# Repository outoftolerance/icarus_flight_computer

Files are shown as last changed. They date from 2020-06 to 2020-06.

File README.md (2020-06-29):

# Icarus Flight Computer

## SERCOM
We make use of the SERCOM feature of the micro by definig two additional serial ports beyond those already defined by default, no other customised use of the SERCOM system is needed for this project.

*Note that when adding serial port interfaces using SERCOM, the TX pin may only reside on either PAD0 or PAD2 of a specific SERCOM interface! This limits the available SERCOM interfaces that we can choose from because some pads are being used for other interfaces (like I2C or SPI).*

The following table shows the pinout for the `ATSAMD21G18A-U` SERCOM and the uses that we are making of these pins for the project. This table was sourced from ADafruit's fantastic guide on using the Feather M0 that can be [found on their website](https://learn.adafruit.com/using-atsamd21-sercom-to-add-more-spi-i2c-serial-ports/overview).

|Microcontroller Pin|Arduino 'Pin'|SERCOM|SERCOM alt|Configured Interface|
|---|---|---|---|--|
|PA00|Used by xtal|SERCOM1.0|||
|PA01|Used by xtal|SERCOM1.1|||
|PB08|A1|SERCOM4.0|||
|PB09|A2|SERCOM4.1|||
|PA04|A3|SERCOM0.0|||
|PA05|A4|SERCOM0.1|||
|PA06|D8|SERCOM0.2|||
|PA07|D9|SERCOM0.3|||
|PA08|D4|SERCOM0.0|SERCOM2.0|Serial3 - Cellular|
|PA09|D3|SERCOM0.1|SERCOM2.1|Serial3 - Cellular|
|PA10|D1|SERCOM0.2|SERCOM2.2|Serial1 - GPS|
|PA11|D0|SERCOM0.3|SERCOM2.3|Serial1 - GPS|
|PB10|D23 / MOSI|SERCOM4.2||SPI - MicroSD|
|PB11|D24 / SCK|SERCOM4.3||SPI - MicroSD|
|PA12|D22 / MISO|SERCOM2.0|SERCOM4.0|SPI - MicroSD|
|PA13|Used by EDBC|SERCOM2.1|SERCOM4.1||
|PA14|D2|SERCOM2.2|SERCOM4.2||
|PA15|D5|SERCOM2.3|SERCOM4.3||
|PA16|D11|SERCOM1.0|SERCOM3.0|Serial2 - Radio|
|PA17|D13|SERCOM1.1|SERCOM3.1||
|PA18|D10|SERCOM1.2|SERCOM3.2|Serial2 - Radio|
|PA19|D12|SERCOM1.3|SERCOM3.3||
|PA20|D6|SERCOM5.2|SERCOM3.2||
|PA21|D7|SERCOM5.3|SERCOM3.3||
|PA22|D20 / SDA|SERCOM3.0|SERCOM5.0|I2C - Sensors|
|PA23|D21 / SCL|SERCOM3.1|SERCOM5.1|I2C - Sensors|
|PA24|Used by USB|SERCOM3.2|SERCOM5.2|Serial - Debug|
|PA25|Used by USB|SERCOM3.3|SERCOM5.3|Serial - Debug|
|PB22|D30 / EDBG TX|SERCOM5.2||Serial5 - APRS|
|PB23|D31 / EDBG RX|SERCOM5.3||Serial5 - APRS|
|PA30|Used by SWCLK|SERCOM1.2|||
|PA31|Used by SWDIO|SERCOM1.3|||
|PB02|A5|SERCOM5.0|||
|PB03|D25 / RX LED|SERCOM5.1|||

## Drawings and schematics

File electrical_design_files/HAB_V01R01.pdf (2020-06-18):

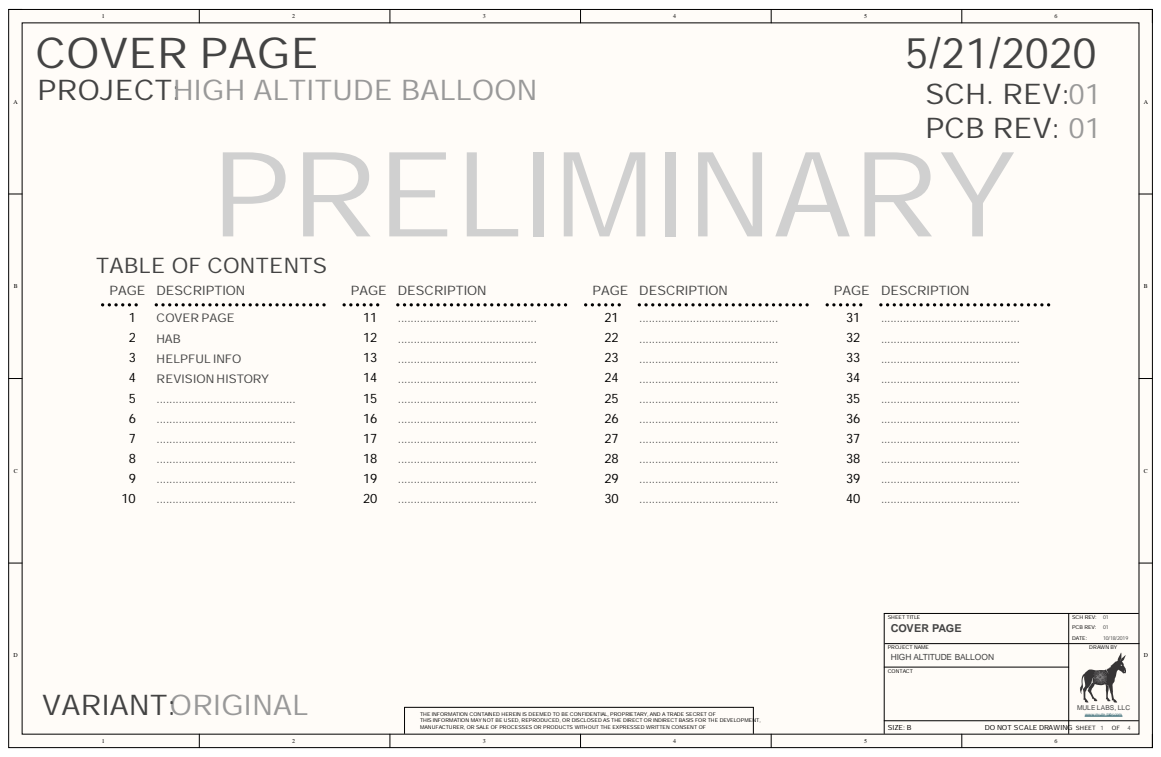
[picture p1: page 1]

SHEET TITLE COVER PAGE | SCH REV: 01 PCB REV: 01 DATE: 10/18/2019

PROJECT NAME HIGH ALTITUDE BALLOON | DRAWN BY MULE LABS, LLC www.mule-labs.com

THE INFORMATION CONTAINED HEREIN IS DEEMED TO BE CONFIDENTIAL, PROPRIETARY, AND A TRADE SECRET OF
THIS INFORMATION MAY NOT BE USED, REPRODUCED, OR DISCLOSED AS THE DIRECT OR INDIRECT BASIS FOR THE DEVELOPMENT,
MANUFACTURER, OR SALE OF PROCESSES OR PRODUCTS WITHOUT THE EXPRESSED WRITTEN CONSENT OF

DO NOT SCALE DRAWING

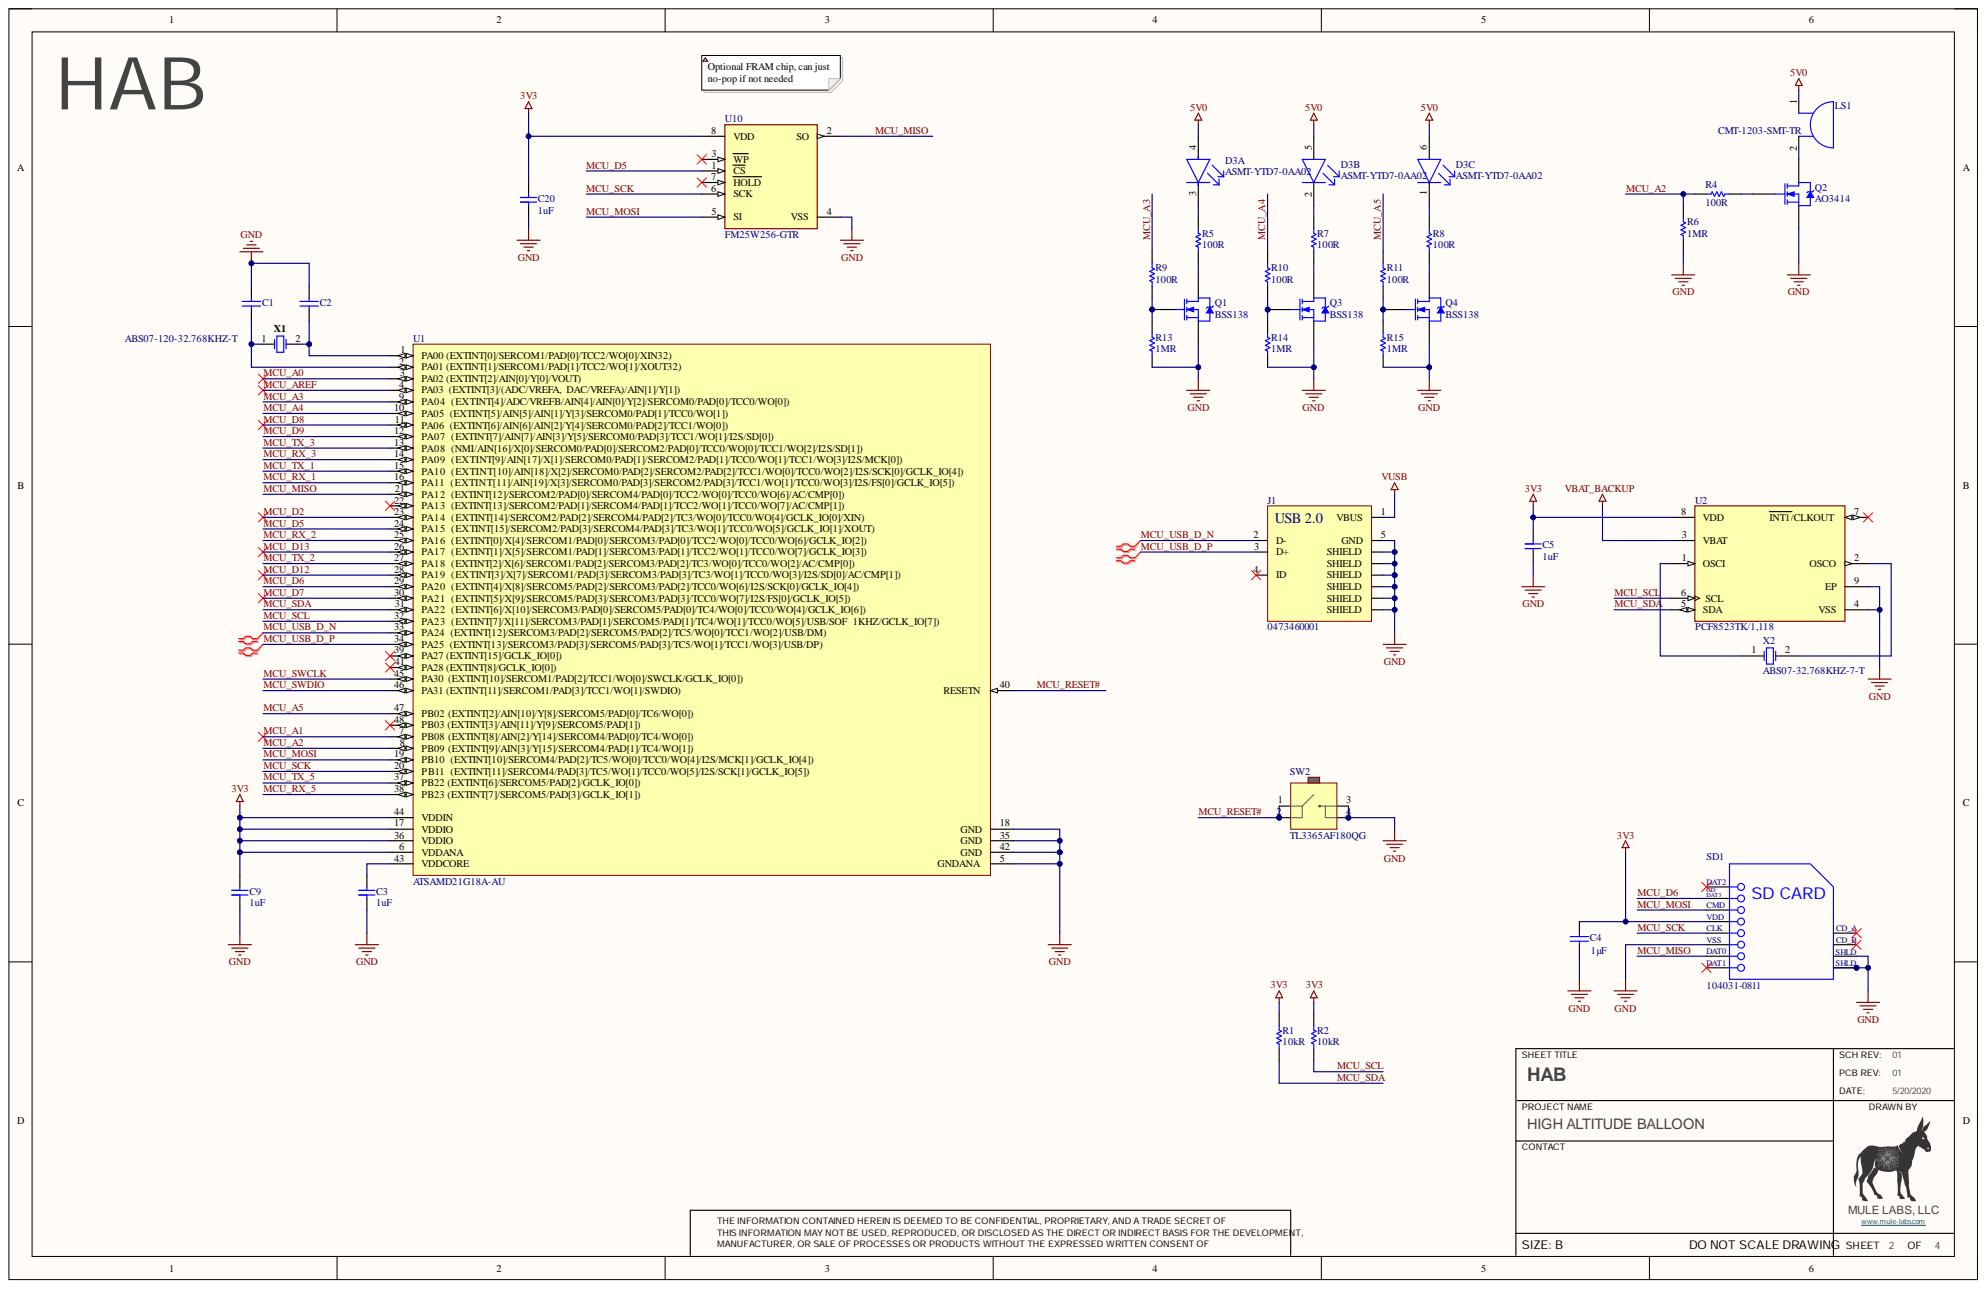
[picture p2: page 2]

3 6 | 3 5 | 1 R 2 0 kR 1 0 kR
6 | 4 2
4 3 | | 5

SHEET T I T L E H A B | SC H REV : 0 1 PCB REV : 0 1 D A TE: 5 /2 0 /2 0 2 0

PR O JEC T N A M E H I G H A LT I T U DE BA L L O O N | D R A W N BY M U L E L A B S , L L C w w w . m u l e-l a b s . c o m

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
D | D
C | C
B | B
A | A
SHEET TITLE HELPFUL | SCH REV: 01 PCB REV: 01 INFO DATE: 10/18/2019
PROJECT NAME HIGH ALTITUDE BALLOON | DRAWN BY MULE LABS, LLC www.mule-labs.com

THE INFORMATION CONTAINED HEREIN IS DEEMED TO BE CONFIDENTIAL, PROPRIETARY, AND A TRADE SECRET OF

MANUFACTURER, OR SALE OF PROCESSES OR PRODUCTS WITHOUT THE EXPRESSED WRITTEN CONSENT OF

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

### SIZE: B

SHEET OF

CONTACT

3 | 4

### DO NOT SCALE DRAWING

# HELPFUL INFO

# SCHEMATIC STATUS:

# PRELIMINARY:

# DRAFT:

# RELEASED:

# CHECKED:

# 'NOT PLACED' COMPONENTS: NET CLASS:

Very early stage of schematic, ignore details.

Nearing completion but has not been checked.

Schematic has been checked by another engineer and there should be no mistakes.

A board with this schematic has been sent to production.

DESIGN NOTE:
Example text for cautionary design notes.

DESIGN NOTE:
Example text for informational design notes .

DESIGN NOTE:
Example text for critical
design notes.

LAYOUT NOTE:
Example text for critical
layout guidelines.

# DESIGN NOTES:

# SHEET TITLE

# LABELING:

# Specific Label

# General Label

# DIFF PAIRS:

PORTS: | NET LABELS: | GLOBALS:

### Components that are to remain on the fabricated PCB but to not be included on the BOM or Assembly drawing are

marked as "NP" for "not placed".

### Ports are used as a means for carrying a signal off of/onto another schematic sheet. The port will always contain information regarding what sheet it is coming from/going to in the form of PAGE#[QUADRANT]. If the port goes to multiple sheets, all sheet

numbers/quadrants will be displayed next to the port.

### Net labels are used to assign human readable names to nets. Net labels can carry off sheet, but should be accompanied with a 'port' symbol if the net leaves the

sheet.

### Related nets are categorized together using the NET CLASS directive. Net classes will be grouped using the

'blanket' direcetive.

### Global symbols/labels are used for power and reference planes. These symbols span across every

schematic sheet in the project.

### Differential pairs have pins/net names that end in '_N'

and '_P'. The 'Differential Pair' directive is used,

### along with a net class specifying the differential impedance, to denote differential pairs on the
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

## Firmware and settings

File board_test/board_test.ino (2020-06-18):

#include <Wire.h>
#include <SPI.h>
#include <SD.h>
#include "Adafruit_FRAM_SPI.h"

#define FRAM_CHIP_SELECT 5
#define SD_CHIP_SELECT 6

int pin_address_book[] = {5, 6, 16, 17, 18, 19};
int i2c_address_book[] = {0x1F, 0x70, 0x76, 0x21, 0x68, 0x40};

Adafruit_FRAM_SPI fram = Adafruit_FRAM_SPI(FRAM_CHIP_SELECT);

uint8_t           addrSizeInBytes = 2; //Default to address size of two bytes
uint32_t          memSize;

int32_t readBack(uint32_t addr, int32_t data) {
    int32_t check = !data;
    int32_t wrapCheck, backup;

    fram.read(addr, (uint8_t*)&backup, sizeof(int32_t));
    fram.writeEnable(true);
    fram.write(addr, (uint8_t*)&data, sizeof(int32_t));
    fram.writeEnable(false);
    fram.read(addr, (uint8_t*)&check, sizeof(int32_t));
    fram.read(0, (uint8_t*)&wrapCheck, sizeof(int32_t));
    fram.writeEnable(true);
    fram.write(addr, (uint8_t*)&backup, sizeof(int32_t));
    fram.writeEnable(false);

    // Check for warparound, address 0 will work anyway
    if (wrapCheck==check)
        check = 0;

    return check;
}

bool testAddrSize(uint8_t addrSize) {
    fram.setAddressSize(addrSize);

    if (readBack(4, 0xbeefbead) == 0xbeefbead)
        return true;
    return false;
}

void setup()
{
    //Set pin modes
    for(int i = 0; i < sizeof(pin_address_book)/sizeof(int); i++)
    {
        pinMode(pin_address_book[i], OUTPUT);
    }

    //Start Wire
    Wire.begin();

    //Wait for serial
    while(!Serial);
    Serial.begin(115200);

    //Print welcome
    Serial.println("Icarus V1.0 Board Test Program");
    Serial.println("--------------------------------");
    Serial.println();
    delay(50);
}

void loop()
{
    int pass_count = 0;
    int fail_count = 0;

    //Check all I2C addresses
    Serial.println("TEST - I2C Address Scan");
    for(int i = 0; i < sizeof(i2c_address_book)/sizeof(int); i++)
    {
        Serial.print("Checking Address: 0x");
        Serial.print(i2c_address_book[i], HEX);
        Serial.print("...    ");

        Wire.beginTransmission(i2c_address_book[i]);
        int error = Wire.endTransmission();

        if (error == 0)
        {
            Serial.println("PASS");
            pass_count++;
        }
        else
        {
            Serial.println("FAIL");
            fail_count++;
        }
    }
    Serial.println();

    //Toggle all output pins and check for function
    Serial.println("TEST - Output Pin Toggle");
    for(int i = 0; i < sizeof(pin_address_book)/sizeof(int); i++)
    {
        Serial.print("Checking Pin: ");
        Serial.print(pin_address_book[i], DEC);
        Serial.print("...    ");

        digitalWrite(pin_address_book[i], HIGH);
        delay(10);
        bool pin_result = digitalRead(pin_address_book[i]);
        digitalWrite(pin_address_book[i], LOW);

        if(pin_result)
        {
            Serial.println("PASS");
            pass_count++;
        }
        else
        {
            Serial.println("FAIL");
            fail_count++;
        }
    }
    Serial.println();

    //Check SD card slot
    Serial.println("TEST - SD Card");
    Serial.print("Initializing card...    ");
    if (SD.begin(SD_CHIP_SELECT)) 
    {
        Serial.println("PASS");
        pass_count++;

        File test_file = SD.open("test.txt", FILE_WRITE);

        Serial.print("Creating file...    ");
        if(test_file)
        {
            Serial.println("PASS");
            pass_count++;

            Serial.print("Deleting file...    ");
            test_file.close();
            if(SD.remove("test.txt"))
            {
                Serial.println("PASS");
                pass_count++;
            }
            else
            {
                Serial.println("FAIL");
                fail_count++;
            }
        }
        else
        {
            Serial.println("FAIL");
            fail_count++;
        }
    }
    else
    {
        Serial.println("FAIL");
        fail_count++;
    }
    Serial.println();

    //Check FRAM
    Serial.println("TEST - FRAM Chip");
    Serial.print("Initializing chip...    ");
    if (fram.begin()) 
    {
        Serial.println("PASS");
        pass_count++;

        Serial.print("Testing chip address size...    ");
        if (testAddrSize(2))
        {
            Serial.println("PASS");
            pass_count++;
            addrSizeInBytes = 2;
        }
        else if (testAddrSize(3))
        {
            Serial.println("PASS");
            pass_count++;
            addrSizeInBytes = 3;
        }
        else if (testAddrSize(4))
        {
            Serial.println("PASS");
            pass_count++;
            addrSizeInBytes = 4;
        }
        else
        {
            Serial.println("FAIL");
            fail_count++;
        }

        Serial.print("Testing chip capacity...    ");
        memSize = 0;

        while (readBack(memSize, memSize) == memSize) 
        {
            memSize += 256;
        }

        if((memSize/0x400) == 256)
        {
            Serial.println("PASS");
            pass_count++;
        }
        else
        {
            Serial.println("FAIL");
            fail_count++;
        }
    }
    else
    {
        Serial.println("FAIL");
        fail_count++;
    }
    Serial.println();

    //Print results
    Serial.println("Board Test Results");
    Serial.println("--------------------------------");
    Serial.print("Passed: ");
    Serial.println(pass_count);
    Serial.print("Failed: ");
    Serial.println(fail_count);

    while(1);
}

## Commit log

2020-06-18 First iteration of board test program
2020-06-18 Moving hardware design files
    [HAB_PANELIZED.PcbDoc, HAB_V01R01.PcbDoc, HAB_V01R01.PrjPCB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]
